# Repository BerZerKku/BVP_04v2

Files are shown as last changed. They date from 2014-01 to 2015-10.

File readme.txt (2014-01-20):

Плата BVP_04v2. 
Cделана в OrCAD 16.6.

Предназначена для использования в АВАНТ К400, АВАНТ Р400М с сэндвичпанелями.

Изменения:
Входы управления подключены к 24В вместо земли.
Изменена подтяжка на +5В сигнала речи для варианта К400 (в варианте с речью, 
подтяжка идет к +5ВА).
Неиспользуемые входы микросхемы DD2 подтянуты к земле через резистор 10кОм.
Сделана возможность использования платы для Р400.
Немного передвинуты линии сигнализаций в верхней части.

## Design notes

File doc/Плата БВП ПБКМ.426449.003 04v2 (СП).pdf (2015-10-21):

№ | Наименование | Корпус | Кол. | Поз. | Примечание
| | | | | ПБКМ.426449.003 ²
Изм | Лист | № докум. | Подп. | Дата
Разраб. | Щеблыкин М.В | | 21.09.15 | Плата БВП 04v2 Спецификация | Лит. «Прософт-Системы» Н.контр. | Лист | Листов
Провер. | Вершинин А.С. | | 21.09.15 | | | 1 | 8

### ООО

Назаренко А.Н. | 21.09.15
Утв. | Чирков А.Г.
1 | Сборочный чертеж
| ПБКМ.426449.003 rev.2 | 1

ДЕТАЛИ
3 | Плата печатная
| BVP_04v2 | 1

ПРОЧИЕ ИЗДЕЛИЯ
5 | Диод BAT54A | SOT-23_3 | 1 | VD18
13 | Дроссель LQH43CN100K03L 10мкГн
| 650мА MURATA | 1812 | 2 | L2,L3

Конденсаторы

19 | чип 0805 X7R 50В 0.1мкФ ±10% | 0805 | 10 | C3,C6,C29-C31,C33-C36,C38
23 | чип 0805 X7R 10В 10мкФ ±10% | 0805 | 2 | C28,C32

Микросхемы

29 | ADuM3402ARWZ AD | SOIC_16 | 1 | DD4
31 | SN74ACT573DW(R) TI
| (74ACT573SC FAIRCHILD,
| M74HCT573M1R(RM13TR) ST) | SOIC_20 | 2 | DD1,DD2
33 | SN74LVC1G14DBV(R, T) TI
| (74LVC1G14GV PANASONIC, NXP) | SOT-23_5 | 1 | DD5

# ПБКМ.426449.003

Лист

2 Изм | Лист | № докум. | Подп. | Дата
41 | Преобразователь напряжения
| TMA 0505S 1Вт +5В TRACO | SIP7_4 | 1 | DA6
45 | Оптрон HCPL-817-300E AVAGO | SMD_4 | 3 | AV1,AV5,AV6

Разъемы

49 | DIN 41612 3*32 96 MR | 96 pins | 2 | X1,X2 | вилка угловая
51 | Разъем PLS-2 | PLS_2 | 2 | X3,X4

Резисторы

55 | чип 0805 51Ом ±5% | 0805 | 4 | R38,R39,R45,R46
61 | чип 0805 1кОм ±5% | 0805 | 1 | R41
63 | чип 0805 2кОм ±5% | 0805 | 3 | R13,R17,R18
67 | чип 0805 10кОм ±5% | 0805 | 5 | R49-R53
73 | чип сборка 1206х4 100 ±5% | 1206 | 5 | RR1,RR2,RR6-RR8 | convex
75 | чип сборка 1206x4 10кОм ±5% | 1206 | 3 | RR3-RR5 | convex

Супрессоры

79 | SM6T6V8CA 6.8В двунаправленный | DO-214AA | 1 | VD1
81 | SM6T30CA 30В двунаправленный | DO-214AA | 1 | VD2

| | | | 3 Изм
Лист | № докум. | Подп. | Дата

Переменные данные для
исполнений:

ВАРИАНТ Р400М

Диоды

5 | BAT54A | SOT-23_3 | 4 | VD3-VD6
7 | Светодиод FYL-5013PURD1C
| красный FORYARD | 2 pins | 7 | VD10-VD16
9 | Светодиод L-53SGD зеленый
| KINGBRIGHT | 2 pins | 1 | VD17
13 | Дроссель LQH43CN100K03L
| 10мкГн 650мА MURATA | 1812 | 1 | L1

Конденсаторы

17 | чип 0805 X7R 50В 1000пФ ±10% | 0805 | 1 | C21
18 | Чип 0805 X7R 50В 0.01мкФ ±10% | 0805 | 1 | C8
19 | чип 0805 X7R 50В 0.1мкФ ±10% | 0805 | 15 | C2,C4,C5,C7,C10-C13,C15,C16,C18,
| | | | C20,C22,C23,C37
21 | чип 0805 X7R 50В 2.2мкФ ±10% | 0805 | 1 | C24
23 | чип 0805 X7R 10В 10мкФ ±10% | 0805 | 8 | C1,C9,C14,C17,C19,C25-C27

Микросхемы

27 | AD8532ARZ AD | SOIC_8 | 2 | DA2,DA5
33 | SN74LVC1G14DBV(R, T) TI
| (74LVC1G14GV PANASONIC, NXP) | SOT-23_5 | 1 | DD3
35 | SSM2167-1RMZ-R7(-REEL) AD | SOIC_10 | 1 | DA4
37 | SSM2301RMZ-R2(-REEL, -REEL7) AD
| | SOIC_8 | 1 | DA3
39 | TS5A3160DBV TI | SOT-23_6 | 1 | DA1

| | | | 4 Изм
Лист | № докум. | Подп. | Дата
51 | Разъем PLS-2 | PLS_2 | 1 | X5

Резисторы

57 | чип 0805 100Ом ±5% | 0805 | 5 | R20,R21,R23,R24,R32
61 | чип 0805 1кОм ±5% | 0805 | 3 | R1,R25,R26
65 | чип 0805 5.1кОм ±5% | 0805 | 7 | R2-R8
67 | чип 0805 10кОм ±5% | 0805 | 4 | R27,R30,R36,R48
69 | чип 0805 20кОм ±5% | 0805 | 3 | R31,R35,R37
71 | чип 0805 100кОм ±5% | 0805 | 3 | R22,R28,R29
85 | Провод МГТФ 0,5 | 1м

ВАРИАНТ К400
7 | Светодиод FYL-5013PURD1C
| красный FORYARD | 2 pins | 2 | VD15,VD16
9 | Светодиод L-53SGD зеленый
| KINGBRIGHT | 2 pins | 1 | VD14
45 | Оптрон HCPL-817-300E AVAGO | SMD_4 | 4 | AV2-AV4,AV7

Резисторы

55 | чип 0805 51Ом ±5% | 0805 | 2 | R40,R47
59 | чип 0805 510Ом ±5% | 0805 | 6 | R9,R11,R12,R42-R44
61 | чип 0805 1кОм ±5% | 0805 | 1 | R6
63 | чип 0805 2кОм ±5% | 0805 | 4 | R14-R16,R19
65 | чип 0805 5.1кОм ±5% | 0805 | 2 | R7,R8

| | | | 5 Изм
Лист | № докум. | Подп. | Дата

ВАРИАНТ Р400

Диоды

5 | BAT54A | SOT-23_3 | 1 | VD5
7 | Светодиод FYL-5013PURD1C
| красный FORYARD | 2 pins | 3 | VD11,VD12,VD16
9 | Светодиод L-53SGD зеленый
| KINGBRIGHT | 2 pins | 1 | VD10
13 | Дроссель LQH43CN100K03L 10мкГн
| 650мА MURATA | 1812 | 1 | L1

Конденсаторы

17 | чип 0805 X7R 50В 1000пФ ±10% | 0805 | 1 | C21
18 | Чип 0805 X7R 50В 0.01мкФ ±10% | 0805 | 1 | C8
19 | чип 0805 X7R 50В 0.1мкФ ±10% | 0805 | 14 | C2,C5,C7,C10-13,C15,C16,C18,C20,
| | | | C22,C23,C37
21 | чип 0805 X7R 50В 2.2мкФ ±10% | 0805 | 1 | C24
23 | чип 0805 X7R 10В 10мкФ ±10% | 0805 | 8 | C1,C9,C14,C17,C19,C25-C27
| Микросхемы
27 | AD8532ARZ AD | SOIC_8 | 2 | DA2,DA5
33 | SN74LVC1G14DBV(R, T) TI
| (74LVC1G14GV PANASONIC, NXP) | SOT-23_5 | 1 | DD3
35 | SSM2167-1RMZ-R7(-REEL) AD | SOIC_10 | 1 | DA4
37 | SSM2301RMZ-R2(-REEL, -REEL7) AD | SOIC_8 | 1 | DA3
39 | TS5A3160DBV TI | SOT-23_6 | 1 | DA1
45 | Оптрон HCPL-817-300E AVAGO | SMD_4 | 1 | AV2
51 | Разъем PLS-2 | PLS_2 | 1 | X5

| | | | 6 Изм
Лист | № докум. | Подп. | Дата

Резисторы

57 | чип 0805 100Ом ±5% | 0805 | 4 | R21,R23,R24,R32
59 | чип 0805 510Ом ±5% | 0805 | 2 | R9,R42
61 | чип 0805 1кОм ±5% | 0805 | 3 | R25,R26,R54
63 | чип 0805 2кОм ±5% | 0805 | 1 | R14
65 | чип 0805 5.1кОм ±5% | 0805 | 3 | R55,R56,R58
67 | чип 0805 10кОм ±5% | 0805 | 4 | R27,R30,R36,R48
69 | чип 0805 20кОм ±5% | 0805 | 3 | R31,R35,R37
71 | чип 0805 100кОм ±5% | 0805 | 3 | R22,R28,R29
85 | Провод МГТФ 0,5 | 0,8м

ВАРИАНТ РЗСК

Диоды

7 | Светодиод FYL-5013PURD1C
| красный FORYARD | 2 pins | 2 | VD15,VD16
9 | Светодиод L-53SGD зеленый
| KINGBRIGHT | 2 pins | 1 | VD14
13 | Дроссель LQH43CN100K03L 10мкГн
| 650мА MURATA | 1812 | 1 | L1

Конденсаторы

17 | чип 0805 X7R 50В 1000пФ ±10% | 0805 | 1 | C21
18 | Чип 0805 X7R 50В 0.01мкФ ±10% | 0805 | 1 | C8
19 | чип 0805 X7R 50В 0.1мкФ ±10% | 0805 | 14 | C2,C5,C7,C10-C13,C15,C16,C18,
| | | | C20,C22,C23,C37
21 | чип 0805 X7R 50В 2.2мкФ ±10% | 0805 | 1 | C24

| | | | 7 Изм
Лист | № докум. | Подп. | Дата
23 | чип 0805 X7R 10В 10мкФ ±10% | 0805 | 8 | C1,C9,C14,C17,C19,C25-C27

Микросхемы

27 | AD8532ARZ AD | SOIC_8 | 2 | DA2,DA5
33 | SN74LVC1G14DBV(R, T) TI
| (74LVC1G14GV PANASONIC, NXP) | SOT-23_5 | 1 | DD3
35 | SSM2167-1RMZ-R7(-REEL) AD | SOIC_10 | 1 | DA4
37 | SSM2301RMZ-R2(-REEL, -REEL7) AD | SOIC_8 | 1 | DA3
39 | TS5A3160DBV TI | SOT-23_6 | 1 | DA1
45 | Оптрон HCPL-817-300E AVAGO | SMD_4 | 4 | AV2-AV4,AV7
51 | Разъем PLS-2 | PLS_2 | 1 | X5

Резисторы

55 | чип 0805 51Ом ±5% | 0805 | 2 | R40,R47
57 | чип 0805 100Ом ±5% | 0805 | 4 | R21,R23,R24,R32
59 | чип 0805 510Ом ±5% | 0805 | 6 | R9,R11,R12,R42-R44
61 | чип 0805 1кОм ±5% | 0805 | 3 | R6,R25,R26
63 | чип 0805 2кОм ±5% | 0805 | 4 | R14-R16,R19
65 | чип 0805 5.1кОм ±5% | 0805 | 2 | R7,R8
67 | чип 0805 10кОм ±5% | 0805 | 4 | R27,R30,R36,R48
69 | чип 0805 20кОм ±5% | 0805 | 3 | R31,R35,R37
71 | чип 0805 100кОм ±5% | 0805 | 3 | R22,R28,R29
85 | Провод МГТФ 0,5 | 0,8м

| | | | 8 Изм
Лист | № докум. | Подп. | Дата

Лист регистрции изменений СП
№ ревизии | № замененных (измененных) страниц | Дата ревизии | Краткое содержание и причина внесения изменений | Примечание
0 | вновь | 18.02.15 | На замену «Плата АВАНТ БВП 4v2»
1 | 1,4,6,7 | 16.09.15 | Для вариантов Р400, Р400м, РЗСК убраны: R33 из поз.65, R34 из поз 69. Изменена ревизия СБ.
2 | 6,7 | 21.10.15 | Для вариантов Р400 и РЗСК длина провода поз.85 уменьшена до 0,8м.

Исполнения:
Р400м – для Р400м;
К400 – для К400;
Р400 – для Р400;
РЗСК – для РЗСК.

Лист регистрции изменений СБ
№ ревизии | № замененных (измененных) страниц | Дата ревизии | Краткое содержание и причина внесения изменений | Примечание
0 | вновь | 18.02.15 | На замену «Плата АВАНТ БВП 4v2»
1 | 1 | 16.09.15 | Убраны резисторы R33, R34.
2 | 1 | 21.10.15 | Пункт ТТ 4г только для варианта Р400м.

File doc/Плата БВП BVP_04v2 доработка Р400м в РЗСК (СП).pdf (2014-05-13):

№ | Наименование | Корпус | Кол. | Поз. | Примечание

# 1 БВП v4.2 доработка Р400м в РЗСК СП

Изм | Лист | № докум. | Подп. | Дата
Разраб. | Щеблыкин М.В | | 13-05-14 | Плата БВП 04v2 Спецификация | Лит. | Лист | Листов
Провер. | Вершинин А.С. | | | | | 1 | 2

## ООО «Прософт-Системы»

Н.контр. | Назаренко А.Н.
Утв. | Чирков А.Г.

1 Сборочный чертеж

| БВП v4.2 доработка Р400м в РЗСК
| rev.1 | 1

СБОРОЧНЫЕ ЕДИНИЦЫ

3 Плата печатная
| BVP_04v2 вариант Р400м | 1

ПРОЧИЕ ИЗДЕЛИЯ

45 | Оптрон HCPL-817-300E AVAGO | SMD_4 | 4 | AV2-AV4,AV7

Резисторы

55 | чип 0805 51Ом ±5% | 0805 | 2 | R40,R47
59 | чип 0805 510Ом ±5% | 0805 | 6 | R9,R11,R12,R42-R44
61 | чип 0805 1кОм ±5% | 0805 | 1 | R6
63 | чип 0805 2кОм ±5% | 0805 | 4 | R14-R16,R19

| | | | | БВП v4.2 доработка Р400м в РЗСК СП | Лист 2 Изм
1
| Лист | № докум. | Подп. | Дата

## Лист регистрции ревизий СП

№ ревизии | № замененных (измененных) страниц | Дата ревизии | Краткое содержание и причина внесения изменений | Примечание
0 | вновь | 08.04.14
1 | 1 | 13.05.14 | Изменена версия сборочного чертежа.

## Лист регистрции ревизий СБ

№ ревизии | № замененных (измененных) страниц | Дата ревизии | Краткое содержание и причина внесения изменений | Примечание
0 | вновь | 08.04.14
1 | 1 | 12.05.14 | Исправлен пункт 4 ТТ. Дополнительно надо удалять VD6.

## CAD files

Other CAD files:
doc/Плата БВП ПБКМ.426449.003 04v2 (СБ).dwg
doc/Плата БВП BVP_04v2 доработка Р400м в РЗСК (СБ).dwg

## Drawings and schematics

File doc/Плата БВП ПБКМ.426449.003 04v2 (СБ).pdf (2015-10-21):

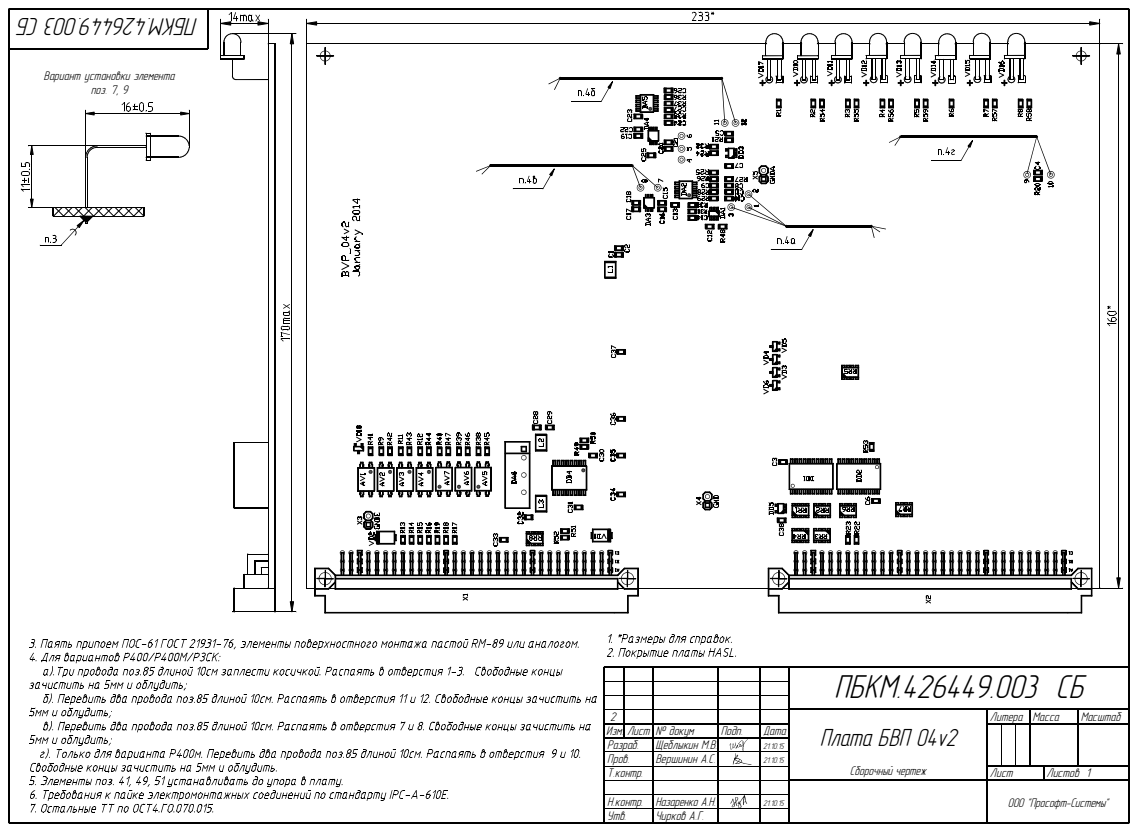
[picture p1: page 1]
Ëèñòîâ 1; Ìàññà; Ìàñøòàá; Ïîäï.; Äàòà; Óòâ.; Í.êîíòð.; Ò.êîíòð.; Ïðîâ.; Ðàçðàá.; Èçì. Ëèñò; ×èðêîâ À.Ã.; Íàçàðåíêî À.Í.; Âåðøèíèí À.Ñ.; Ùåáëûêèí Ì.Â.; № äîêóì; Ëèñò; Ëèòåðà; ÏÁÊÌ.426449.003 ÑÁ; Ïëàòà ÁÂÏ 04v2; ïîç. 7, 9

Âàðèàíò óñòàíîâêè ýëåìåíòà

Ñáîðî÷íûé ÷åðòåæ

ÎÎÎ "Ïðîñîôò-Ñèñòåìû"

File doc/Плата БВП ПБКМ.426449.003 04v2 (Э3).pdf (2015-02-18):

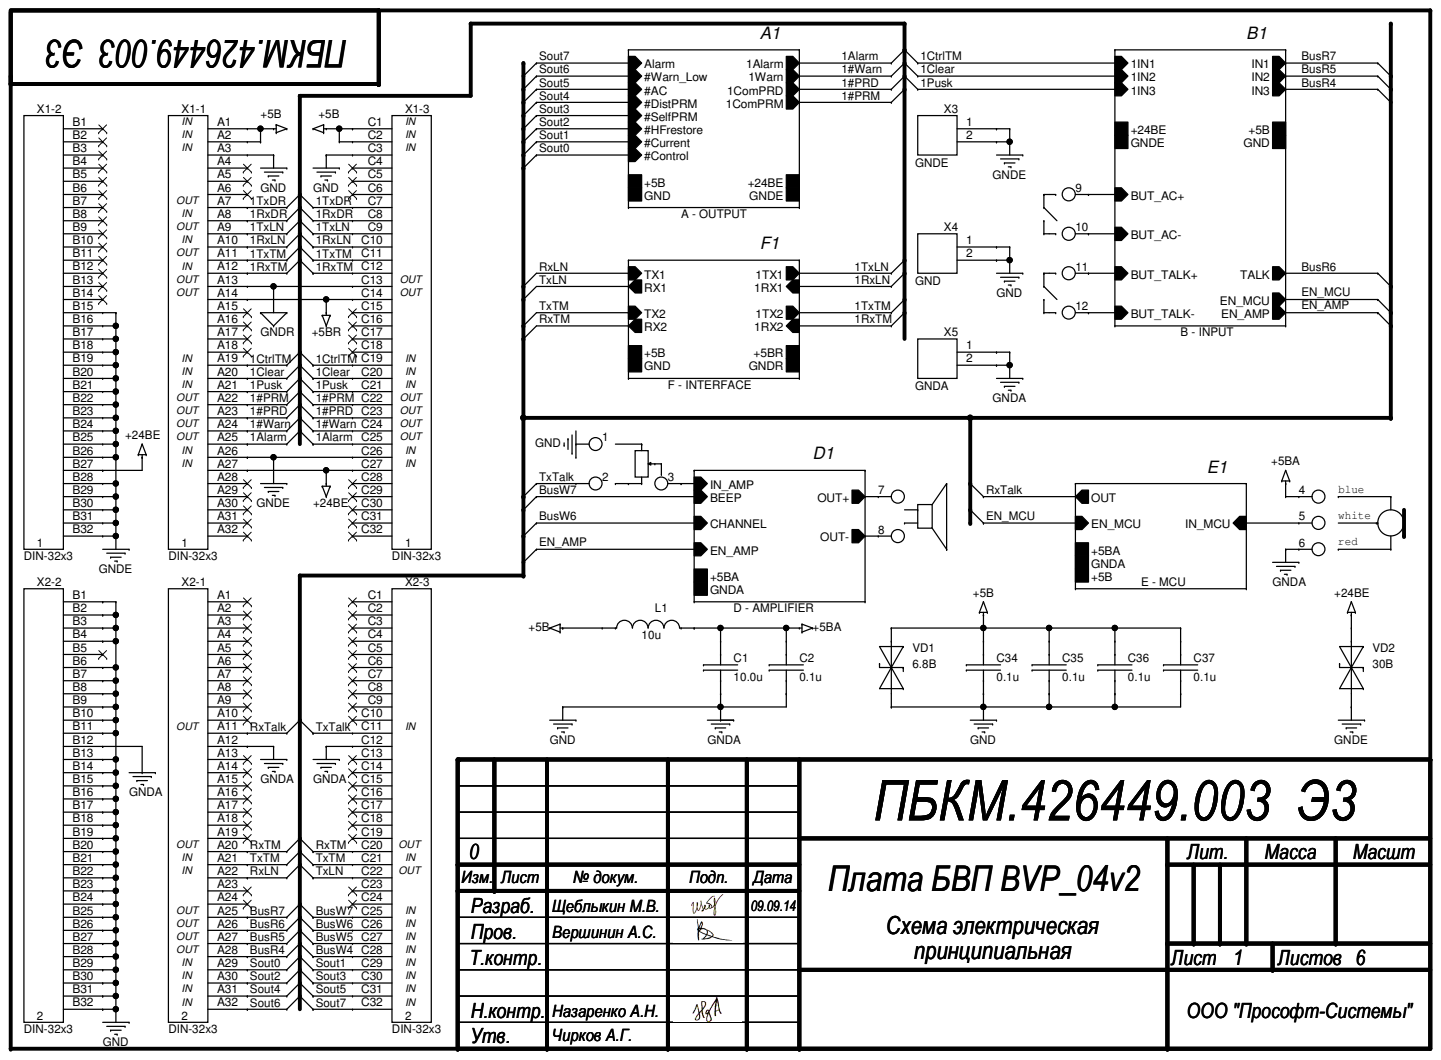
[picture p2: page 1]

ПБКМ.426449.003 Э3 ПБКМ.426449.003 Э3 ПБКМ.426449.003 Э3

0 | | | | | Плата БВП BVP_04v2 Плата БВП BVP_04v2 Плата БВП BVP_04v2 Схема электрическая Схема электрическая Схема электрическая | Лит. | Масса Масса Масса | Масшт Масшт Масшт
Изм. Изм. Изм. | Лист Лист Лист | № докум. № докум. № докум. | Подп. Подп. Подп. | Дата Дата Дата
Разраб. Разраб. Разраб. | | Щеблыкин М.В. Щеблыкин М.В. Щеблыкин М.В. | | 09.09.14 09.09.14 09.09.14
Пров. Пров. Пров. | | Вершинин А.С. Вершинин А.С. Вершинин А.С.
принципиальная Т.контр. принципиальная Т.контр. принципиальная Т.контр. | Лист Лист Лист 1 6 1 6 1 6 | Листов Листов Листов

Н.контр. Н.контр. Н.контр. | Назаренко А.Н. Назаренко А.Н. Назаренко А.Н.
Утв. Утв. Утв. | Чирков А.Г. Чирков А.Г. Чирков А.Г.

ООО "Прософт-Системы" ООО "Прософт-Системы" ООО "Прософт-Системы"

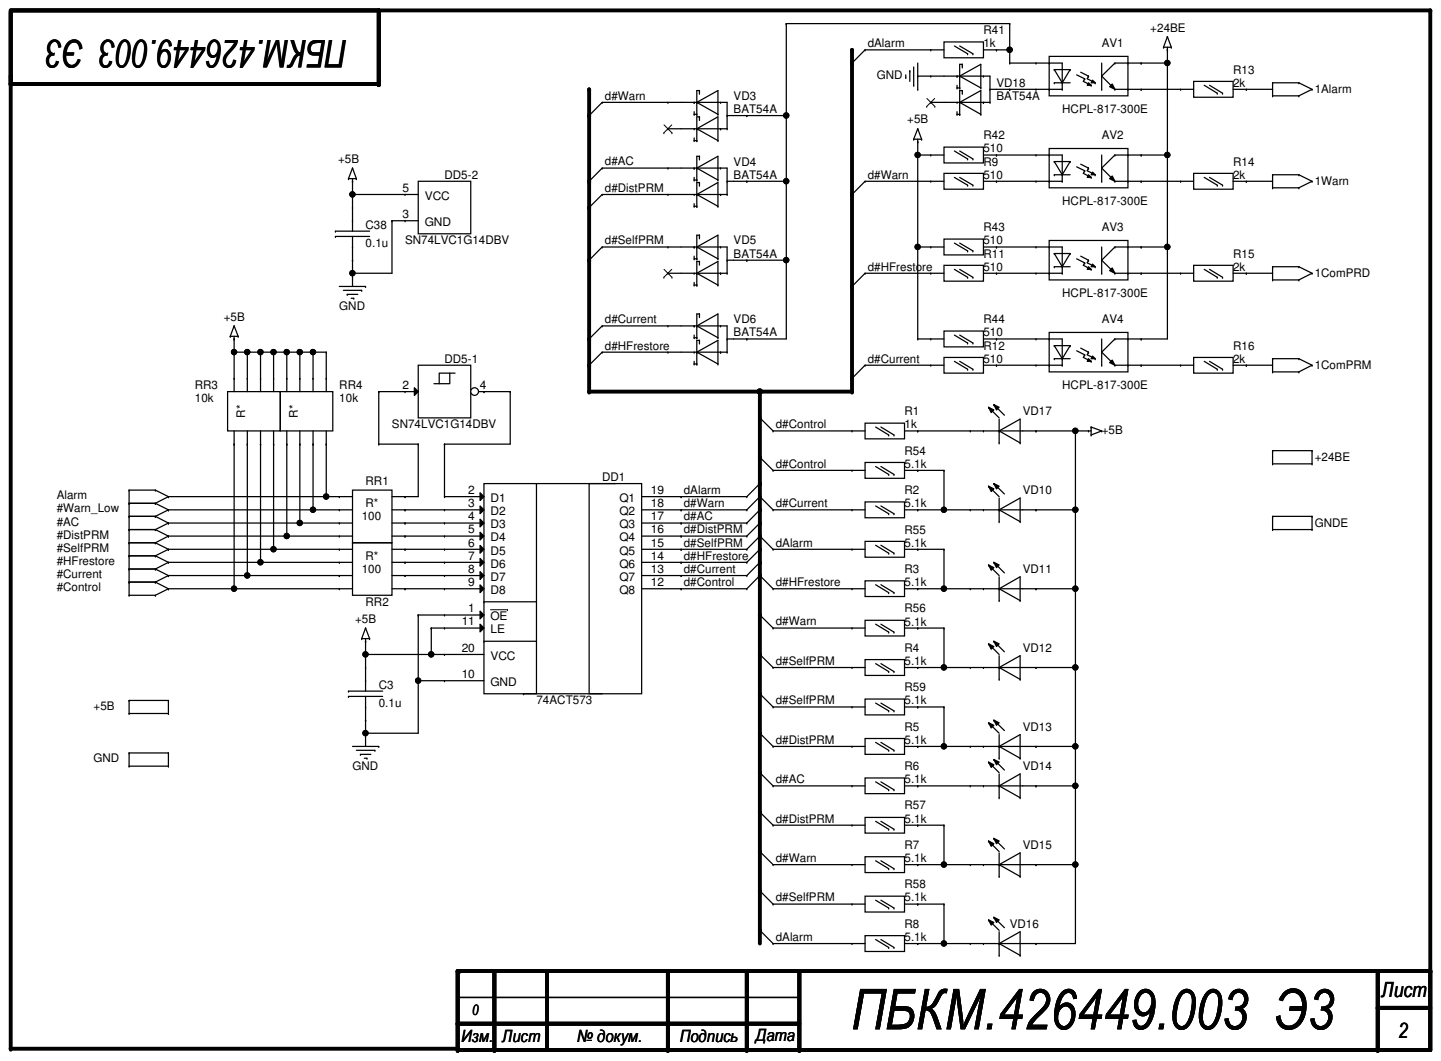
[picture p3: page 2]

Лист ПБКМ.426449.003 Э3 Лист ПБКМ.426449.003 Э3 Лист ПБКМ.426449.003 Э3 2 ⁰ Изм. 2 ⁰ Изм. 2 ⁰

Лист | № докум. | Подпись | Дата

Изм. | Лист | № докум. | Подпись | Дата

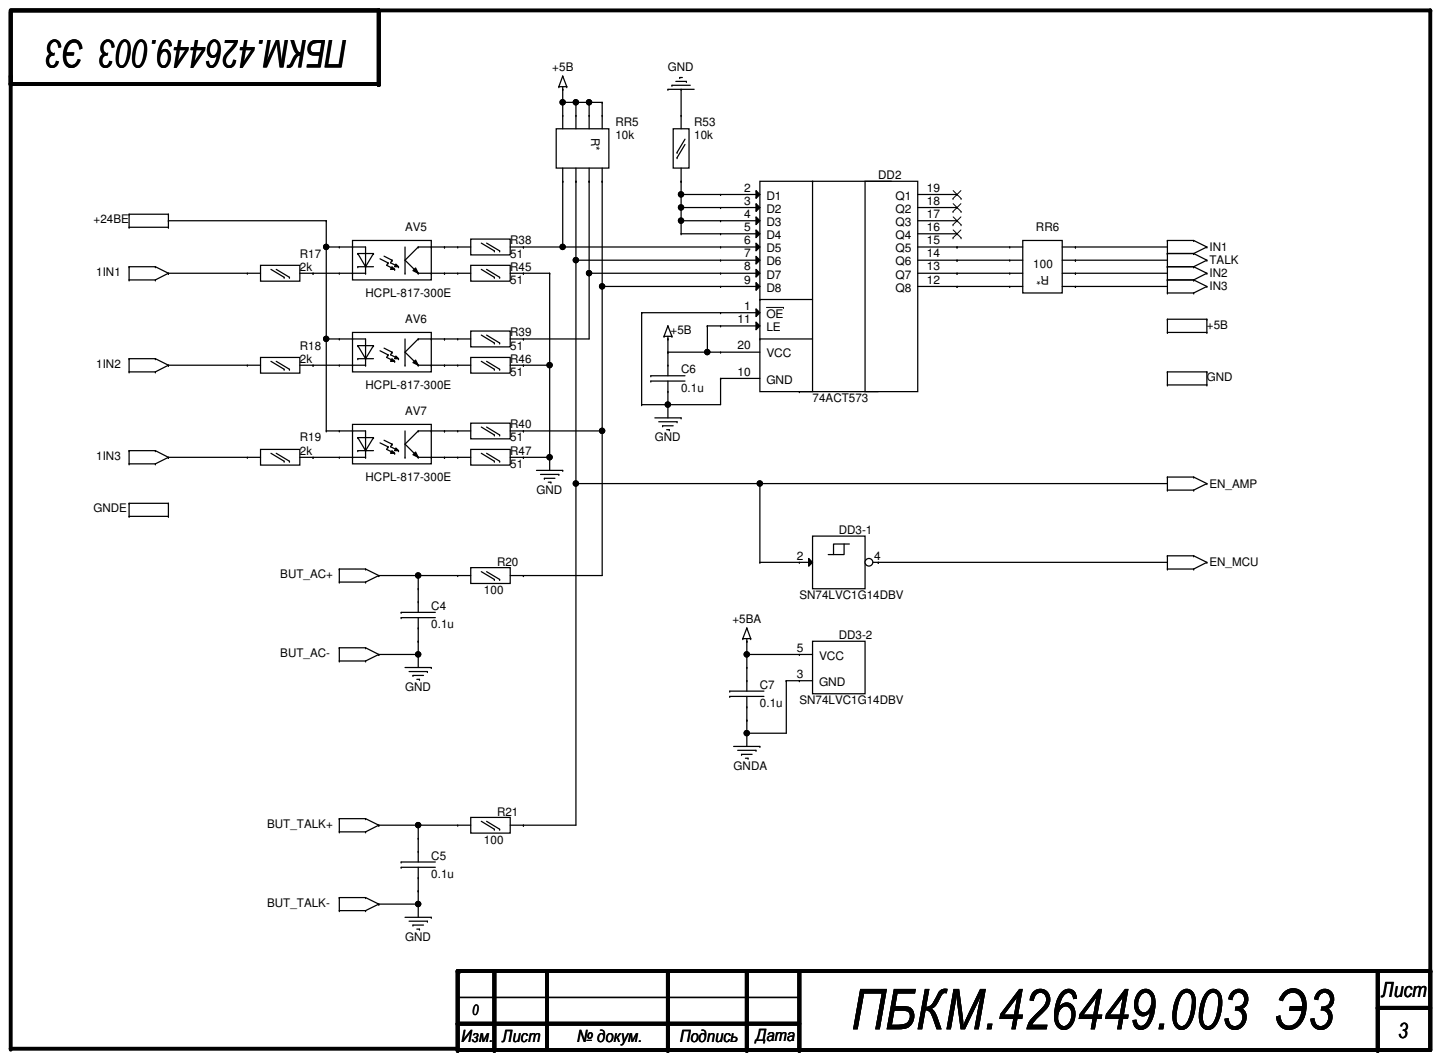
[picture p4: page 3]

Лист ПБКМ.426449.003 Э3 Лист ПБКМ.426449.003 Э3 Лист ПБКМ.426449.003 Э3 3 ⁰ Изм. 3 ⁰ Изм. 3 ⁰

Лист | № докум. | Подпись | Дата

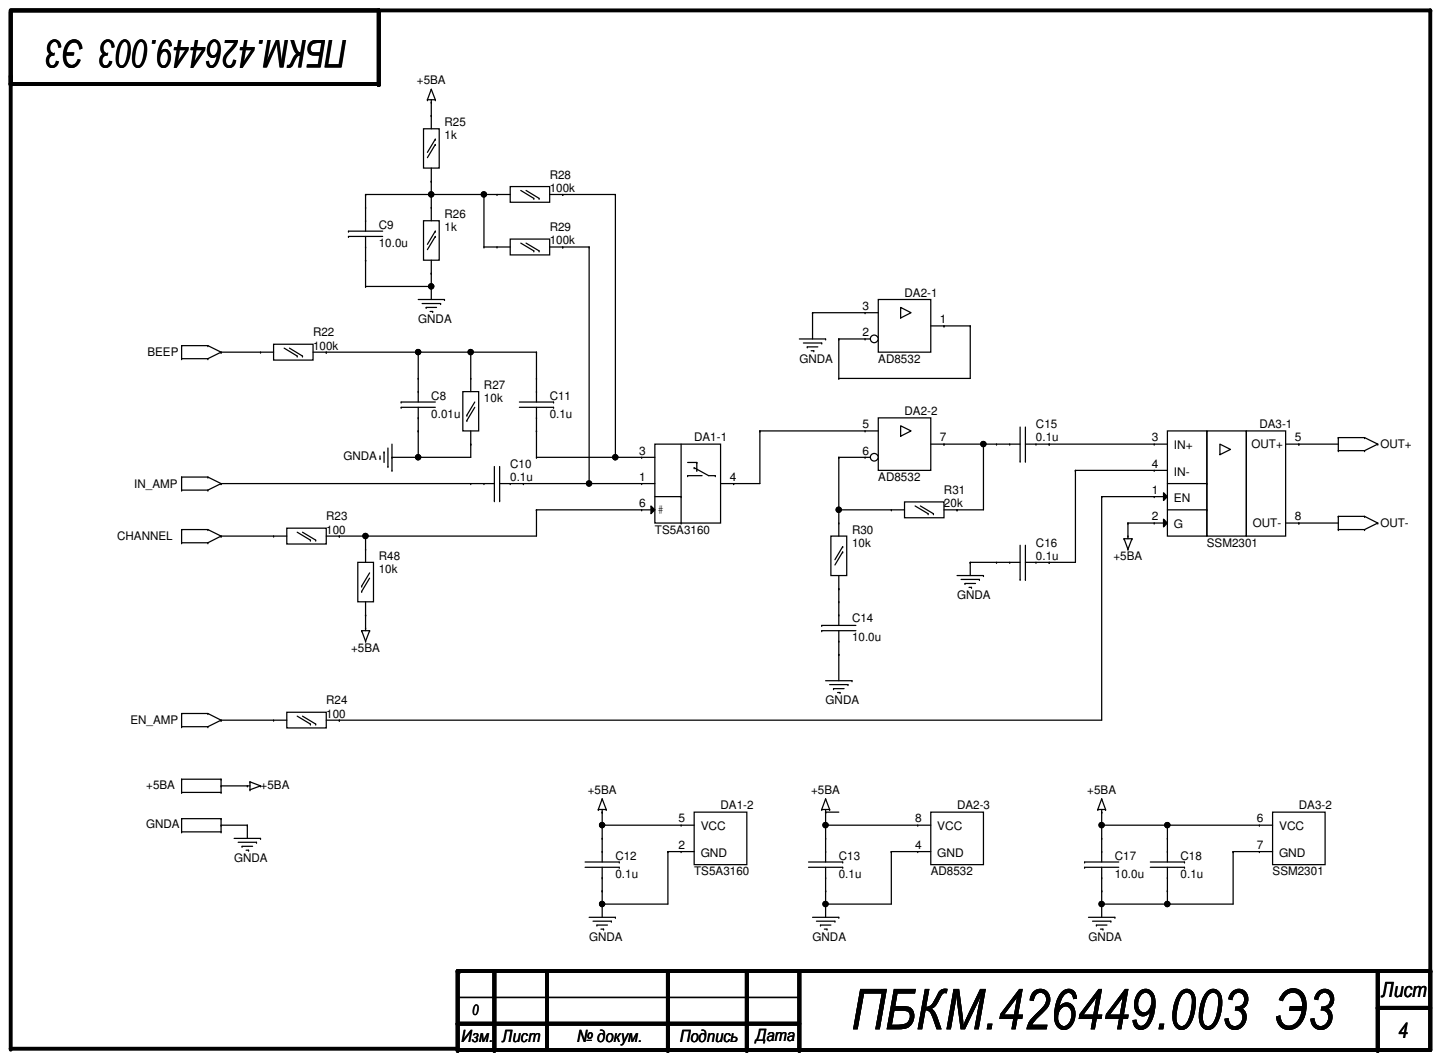
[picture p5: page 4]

Лист ПБКМ.426449.003 Э3 Лист ПБКМ.426449.003 Э3 Лист ПБКМ.426449.003 Э3 4 ⁰ Изм. 4 ⁰ Изм. 4 ⁰

Лист | № докум. | Подпись | Дата

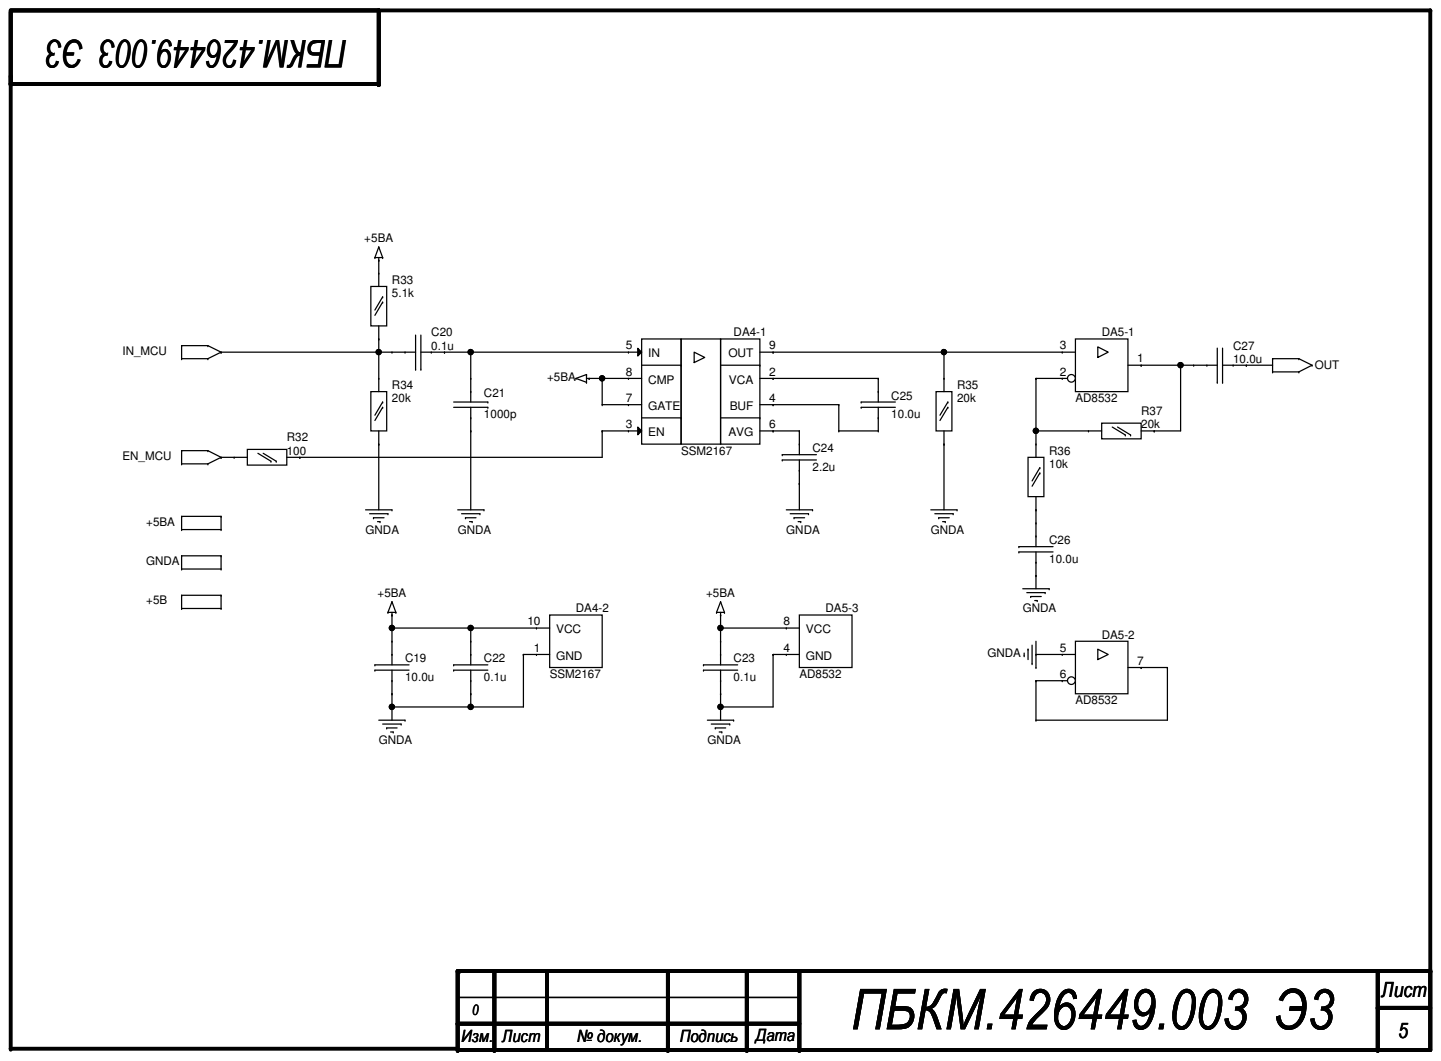
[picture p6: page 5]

Лист ПБКМ.426449.003 Э3 Лист ПБКМ.426449.003 Э3 Лист ПБКМ.426449.003 Э3 5 ⁰ Изм. 5 ⁰ Изм. 5 ⁰

Лист | № докум. | Подпись | Дата

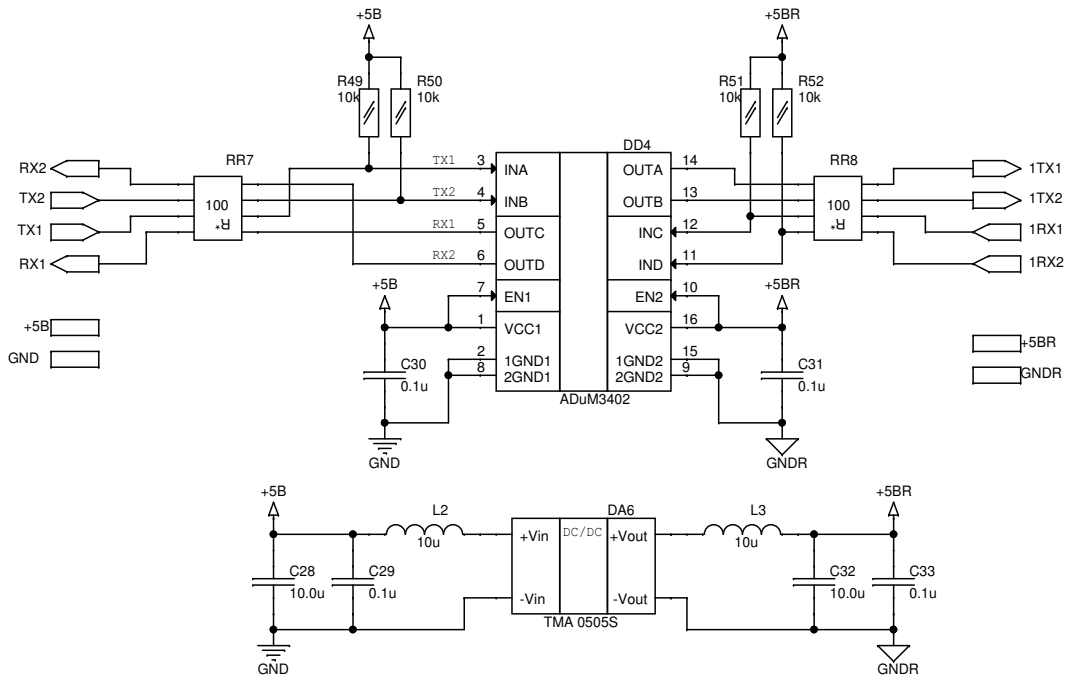
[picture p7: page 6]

Лист ПБКМ.426449.003 Э3 Лист ПБКМ.426449.003 Э3 Лист ПБКМ.426449.003 Э3 6 ⁰ Изм. 6 ⁰ Изм. 6 ⁰

Лист | № докум. | Подпись | Дата

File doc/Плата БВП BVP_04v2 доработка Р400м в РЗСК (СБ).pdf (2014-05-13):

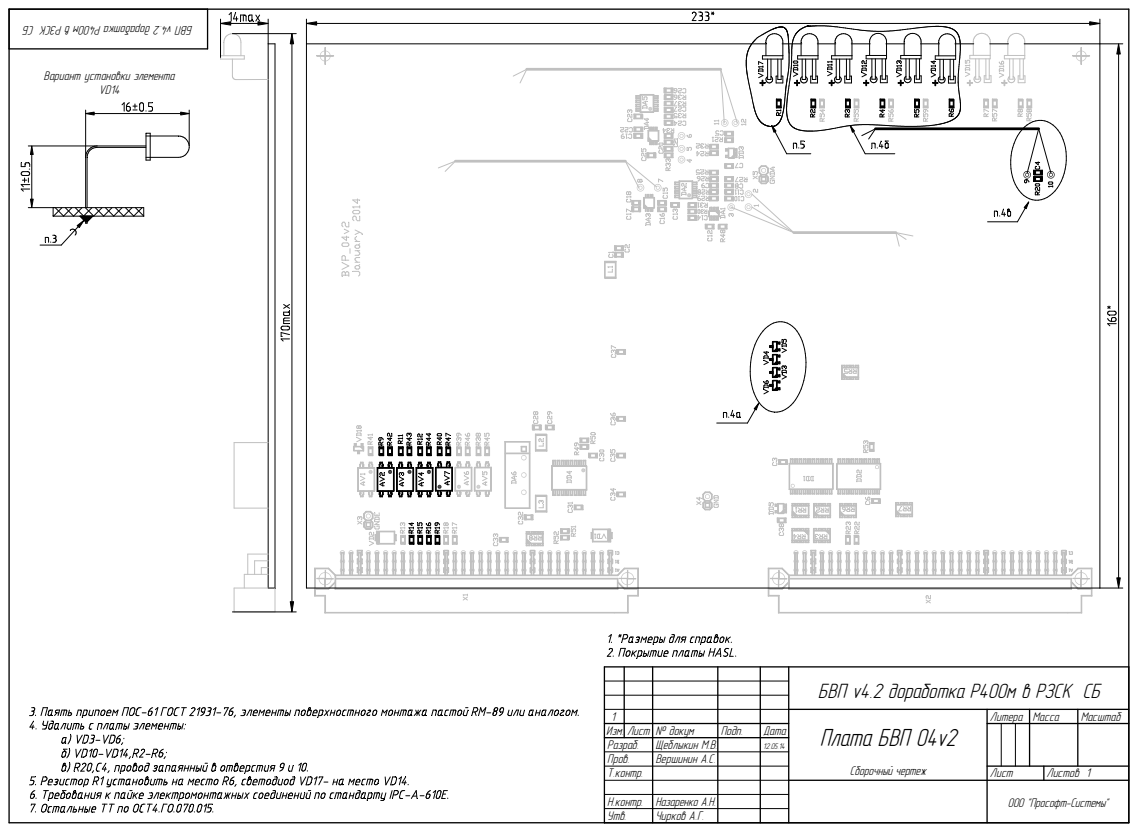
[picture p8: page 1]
Ëèñòîâ 1; Ìàññà; Ìàñøòàá; Ïîäï.; Äàòà; Óòâ.; Í.êîíòð.; Ò.êîíòð.; Ïðîâ.; Ðàçðàá.; Èçì. Ëèñò; ×èðêîâ À.Ã.; Íàçàðåíêî À.Í.; Âåðøèíèí À.Ñ.; Ùåáëûêèí Ì.Â.; № äîêóì; Ëèñò; Ëèòåðà; Ïëàòà ÁÂÏ 04v2

Âàðèàíò óñòàíîâêè ýëåìåíòà

ÁÂÏ v4.2 äîðàáîòêà Ð400ì â ÐÇÑÊ ÑÁ

Ñáîðî÷íûé ÷åðòåæ

ÎÎÎ "Ïðîñîôò-Ñèñòåìû"

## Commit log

2014-01-20 Вновь.
    [BVP_04V2.DSN, BVP_04V2.brd]
2014-01-20 Схема сделана универсальная, подходящая и для использования в Р400 с текущим клеммником (но требуется новая передняя панель)
    [BVP_04V2.DSN]
2014-01-20 Элементы расставлены на плате. Нужна прическа.
    [BVP_04V2.DSN, BVP_04V2.brd]
2014-01-21 Доделана разводка. Созданы файлы для заказа.
    [BVP_04V2.brd, nc_param.txt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]
2014-01-21 Исправлена шелкография.
    [BVP_04V2.DSN, BVP_04V2.brd]
2014-01-21 Добавлен файл настроек герберов.
    [art_param.txt]
2014-01-27 Добавлены СП и СБ.
    [BVP_04V2.DSN, Плата БВП BVP_04v2 (СБ).dwg]
2014-01-27 Обновлен сборочник в общем документе.
2014-02-19 В СП для Р400/Р400м добавлен провод МГТФ 0.5 (поз. 81).
2014-02-19 В СП и ТТ на СБ позиция провода МГТФ изменена на 85.
    [Плата БВП BVP_04v2 (СБ).dwg]
2014-02-19 Провод поз.85 в варианте Р400м перенесен с 3 стр, на 4. На СБ поставил дату изменения ревизии.
    [Плата БВП BVP_04v2 (СБ).dwg]
2014-02-19 Из основного варианта убраны резисторы поз.65 R7 и R8.
2014-03-25 На схеме исправлены цвета проводов для подключения микрофона.
    [BVP_04V2.DSN]
2014-04-08 Добавлена документация для доработки плат Р400м в РЗСК.
2014-04-17 Начата работа над сборочным чертежом для блока БВП.
    [Блок БВП BVP_04v2 (СБ).dwg, Плата БВП BVP_04v2 доработка Р400м в РЗСК (СБ).dwg]
2014-05-13 На сборочнике доработки исправлена ошибка, необходимо дополнительно удалять диод VD6.
    [Плата БВП BVP_04v2 доработка Р400м в РЗСК (СБ).dwg]
2014-05-21 Сборочник на блок перенесен в отдельный каталог.
    [Блок БВП BVP_04v2 (СБ).dwg]
2014-05-27 CП rev.2 СБ rev.2 Добавлен вариант исполнения РЗСК. Шрифт СП заменен на Consolas.
    [Плата БВП BVP_04v2 (СБ).dwg]
2014-09-09 В вариантах Р400, Р400м, РЗСК изменился номинал конденсатора C8 с 1нФ на 10нФ.
    [BVP_04V2.DSN]
2015-02-18 На схему добавлены рамки. Изменен децимальный номер документации.
    [BVP_04V2.DSN, Плата БВП BVP_04v2 (СБ).dwg, Плата БВП ПБКМ.426449.003 04v2 (СБ).dwg]
2015-02-18 В СБ и СП добавлены подписи.
    [Плата БВП ПБКМ.426449.003 04v2 (СБ).dwg]
2015-09-16 На схеме добавлена надпись о пайке резисторов R33, R34. Эти же резисторы убраны из СП и СБ.
    [BVP_04V2.DSN, Плата БВП ПБКМ.426449.003 04v2 (СБ).dwg]
2015-10-21 Провод для кнопки паяется только в варианте Р400м.
    [Плата БВП ПБКМ.426449.003 04v2 (СБ).dwg]
2015-10-21 Убрана лишняя строка в СП.
    [Плата БВП ПБКМ.426449.003 04v2 (СБ).dwg]
